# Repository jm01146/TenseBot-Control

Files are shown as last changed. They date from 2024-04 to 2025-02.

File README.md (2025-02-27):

# TenseBot-Control
FIU EE Senior Design Project for Team 13 Spring 2024 (We won first place not important but I am proud)

Team Members:
* Dr.Pozdin (Mentor) email: vpozdin@fiu.edu
* John Marcial (Team Leader) email: jmarc114@fiu.edu
* Jorge Habib (Team Member) email: jhabi006@fiu.edu
* Daniel Rodriguez (Team Member) email: jrodr1405@fiu.edu
* Vivish Gieowar-Singh (Team Member) email: vgieo001@fiu.edu
* Carlos Sanabria (Team Member) email: csana011@fiu.edu
  
Sponsored by: Dr. Kaur and the FIU RDF Lab

These are the components we used for the robot we created: HC-06 Bluetooth Module, Aa4988 motor driver, Pololu 12V, 2.2A Step-Down Voltage Regulator D24V22F12, and Stepper NEMA 17 motors
circuit

The main python code need to activate the control software is TenseBotApp.py the other python files are utilzed as the backend processes of the control software.
The ino file is for the arduino you plan to use and you can modify the steps it takes but the logic is uses should remain untouched unless you modified the amount of motors in use.

For using the device this link shows the usage cases for this control software. https://www.youtube.com/watch?v=2kFFXKGkytE

However not in the video was how the color detection works. 
You can choose what color you want to detect and the robot will respond accordingly.
This is our figure to showcase the color option.


The entire GUI is customizable for three reasons: If you want to add more idenifcation features like YoLo, or object detection, If you want to add more movement directions for different types of robots, If you don't like the color, because why not.

Last but not least. We created a shield to reduce the amount of wiring needed for the project. This allows the entire series of components to be on one platform and easily replaceable if broken.

# NOTE: The polarity of the XT60 is flipped meaning if you tried to connect it to the 12V regulator it will pop it I need to remake the shield board

In case there becomes a need to make more here is the entire Gerber file to make them and modify if you need.
We are also adding the mounting plate to hold the nema 17 motors and arduino.

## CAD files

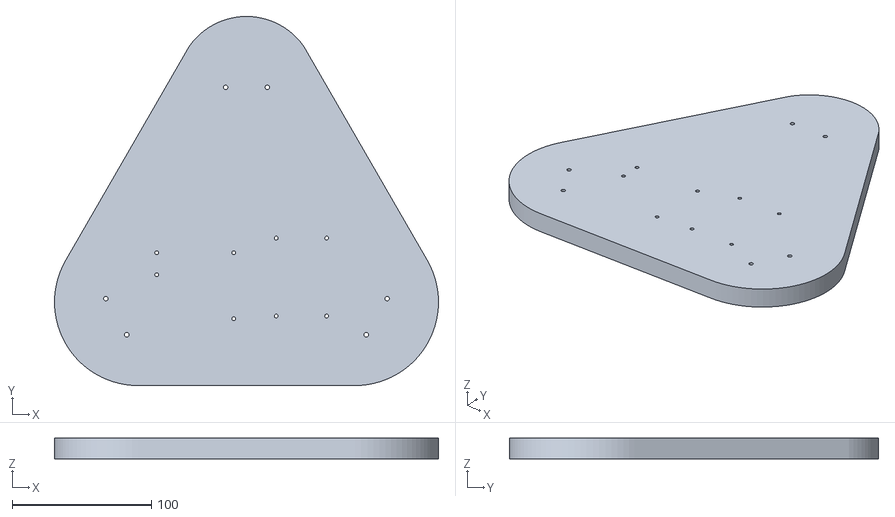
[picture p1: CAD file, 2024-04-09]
Tensegrity Delta Frame v2.stl
275.9 x 265.2 x 15.0

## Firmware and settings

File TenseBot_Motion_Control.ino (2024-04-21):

//Importing Libraries
#include <AccelStepper.h>
#include <MultiStepper.h>
#include <SoftwareSerial.h>

//Conenction to the Bluetooth Module HC-06
SoftwareSerial HC06(10, 11);

// (Type of driver: with 2 pins, STEP, DIR)
AccelStepper stepper1(1, 4, 5);
AccelStepper stepper2(1, 6, 7);
AccelStepper stepper3(1, 8, 9);

MultiStepper steppersControl;

// Setting 3 motor posistions to modify
long gotoposition[3];

// Creating limits for the robot to operate
const int MIN = 0;
const int MAX_LIMIT = 650;

void setup() {
  // Set communications for possible HC06 or Serial
  HC06.begin(9600);
  Serial.begin(9600);

  // Setting the max speed for the motors
  stepper1.setMaxSpeed(200);
  stepper2.setMaxSpeed(200);
  stepper3.setMaxSpeed(200);

  // Creating the family to move unianimously
  steppersControl.addStepper(stepper1);
  steppersControl.addStepper(stepper2);
  steppersControl.addStepper(stepper3);
}

void loop() {
  if (HC06.available()) {
    String data = HC06.readStringUntil('\n');
    
    // If the received data length is 1, it's a command
    if (data.length() == 1) {
      char command = data[0];
      adjustPosition(command);
    } 
    else {
      int x = 0, y = 0;
      sscanf(data.c_str(), "%d,%d", &x, &y);
      adjustPosition(x, y);
    }
    steppersControl.moveTo(gotoposition);
  }
  steppersControl.runSpeedToPosition();
}

// Creating function to move via character command
void adjustPosition(char command) {
  switch(command) {
    // Foward command
    case 'F':
      gotoposition[0] = 0;
      gotoposition[1] = 250;
      gotoposition[2] = 150;
      break;
    // Backward command
    case 'B':
      gotoposition[0] = 200;
      gotoposition[1] = 0;
      gotoposition[2] = 0;
      break;
    // Left command
    case 'L':
      gotoposition[0] = 100;
      gotoposition[1] = 200;
      gotoposition[2] = 0;
      break;
    // Right command
    case 'R':
      gotoposition[0] = 100;
      gotoposition[1] = 0;
      gotoposition[2] = 250;
      break;
    // Home command
    case 'H':
      gotoposition[0] = 0;
      gotoposition[1] = 0;
      gotoposition[2] = 0;
      break;
    default:
      break;
  }
}

// Fucntion to move via XY coordinates with color detection code
void adjustPosition(int x, int y) {
  if (x > 320 && y > 240) {
    gotoposition[0] = 0;
    gotoposition[1] = constrain(gotoposition[1] + (y - 240), MIN, MAX_LIMIT);
    gotoposition[2] = constrain(gotoposition[2] + (x - 320), MIN, MAX_LIMIT);
  } else if (x > 320 && y < 240) {
    gotoposition[0] = constrain(gotoposition[0] + (240 - y), MIN, MAX_LIMIT);
    gotoposition[1] = 0;
    gotoposition[2] = constrain(gotoposition[2] + (x - 320), MIN, MAX_LIMIT);
  } else if (x < 320 && y > 240) {
    gotoposition[0] = 0;
    gotoposition[1] = constrain(gotoposition[1] + (320 - x), MIN, MAX_LIMIT);
    gotoposition[2] = constrain(gotoposition[2] + (y - 240), MIN, MAX_LIMIT);
  } else if (x < 320 && y < 240) {
    gotoposition[0] = constrain(gotoposition[0] + (240 - y), MIN, MAX_LIMIT);
    gotoposition[1] = constrain(gotoposition[1] + (320 - x), MIN, MAX_LIMIT);
    gotoposition[2] = 0;
  } else {
    gotoposition[0] = 0;
    gotoposition[1] = 0;
    gotoposition[2] = 0;
  }
}

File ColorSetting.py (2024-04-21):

# Importing Libraries
import numpy as np
import cv2


# Creating the class for the color detection for the GUI
class Color:
    def __init__(self):
        super().__init__()
        self.lowerLimit = []
        self.higherLimit = []
        self.lowerLimitRed = []
        self.higherLimitRed = []
        self.colorInput = None
        self.mask = None
        self.maskRed = None

    # Setting the lower and upper limits for the OpenCV color detection based on GUI selection
    def color_detect(self, gui_color, hsv):
        self.colorInput = gui_color
        if gui_color == 'Yellow':
            self.lowerLimit = np.array([20, 50, 50], dtype=np.uint8)
            self.higherLimit = np.array([50, 255, 255], dtype=np.uint8)
            self.mask = cv2.inRange(hsv, self.lowerLimit, self.higherLimit)
        elif gui_color == 'Red':
            self.lowerLimit = np.array([0, 150, 150], dtype=np.uint8)
            self.higherLimit = np.array([10, 255, 255], dtype=np.uint8)
            self.lowerLimitRed = np.array([170, 150, 150], dtype=np.uint8)
            self.higherLimitRed = np.array([180, 255, 255], dtype=np.uint8)
            self.mask = cv2.inRange(hsv, self.lowerLimit, self.higherLimit)
            self.maskRed = cv2.inRange(hsv, self.lowerLimitRed, self.higherLimitRed)
            self.mask = self.mask + self.maskRed
        elif gui_color == 'Blue':
            self.lowerLimit = np.array([100, 100, 100], dtype=np.uint8)
            self.higherLimit = np.array([130, 255, 255], dtype=np.uint8)
            self.mask = cv2.inRange(hsv, self.lowerLimit, self.higherLimit)
        elif gui_color == 'Green':
            self.lowerLimit = np.array([50, 50, 50], dtype=np.uint8)
            self.higherLimit = np.array([90, 255, 255], dtype=np.uint8)
            self.mask = cv2.inRange(hsv, self.lowerLimit, self.higherLimit)
        return self.mask

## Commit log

2024-03-14 Update GUI_app.py
    got tired of deleting the same file name over and over and over
2024-03-14 Update GUI_app.py
    Added camera feature with toggle color detection
2024-04-21 Update and rename MotorControl.ino to TenseBot_Motion_Control.ino
